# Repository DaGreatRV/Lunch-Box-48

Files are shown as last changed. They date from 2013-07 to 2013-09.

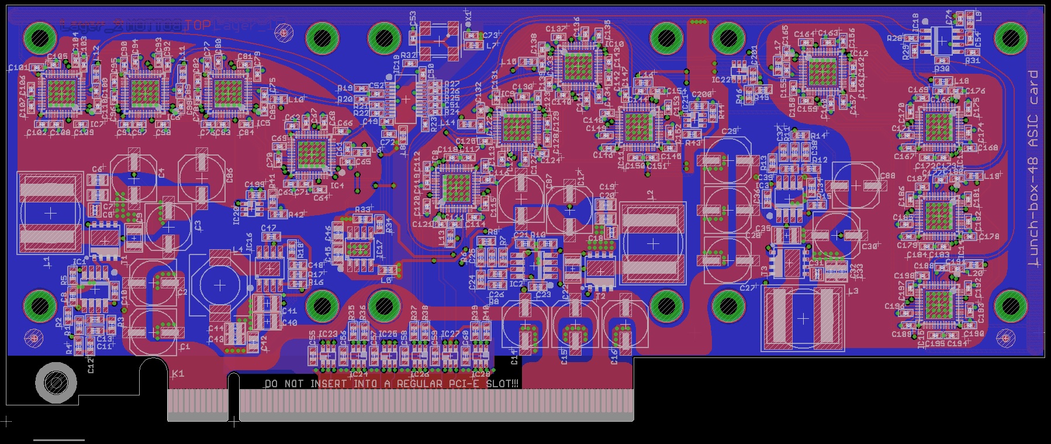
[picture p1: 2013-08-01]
ASIC_board/ASIC_card_overview.jpg

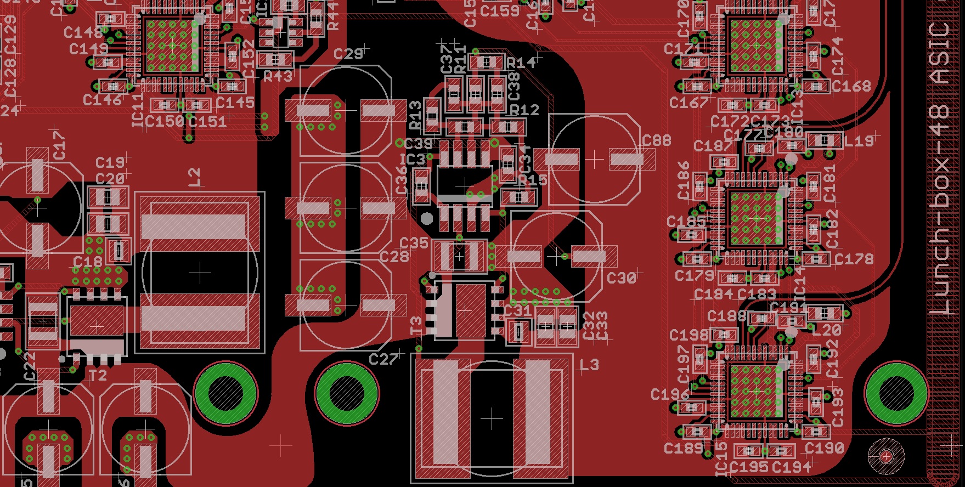
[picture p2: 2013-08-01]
ASIC_board/ASIC_card_detail1.jpg

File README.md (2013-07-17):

Lunch-Box-48
============

A small Avalon based miner

See the thread on bitcointalk/simple machines forum:
https://bitcointalk.org/index.php?topic=219489.0

Terms of use:
I will not take any responsibility for the use, misuse and/or functionality of the work done in this repository.
You are allowed to use and modify the designs in this repository, please do credit me.
If you modify the design(s), please share them and credit me.
You are allowed to use my designs to build a device for private and/or prototype purposes.
If you would like to use this work for commercial purposes(i.e. manufactor and/or selling it), contact me and we can discuss some form of compensation.

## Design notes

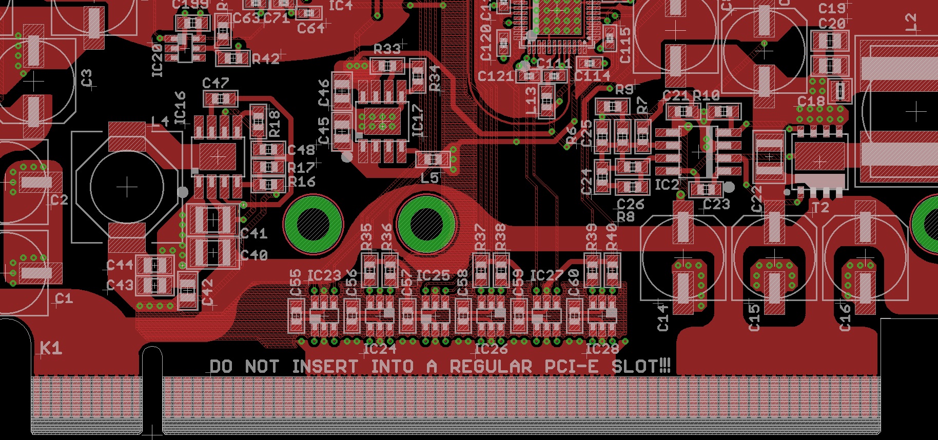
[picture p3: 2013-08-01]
ASIC_board/ASIC_card_detail2.jpg

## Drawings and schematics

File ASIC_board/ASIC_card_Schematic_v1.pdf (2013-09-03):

A

A

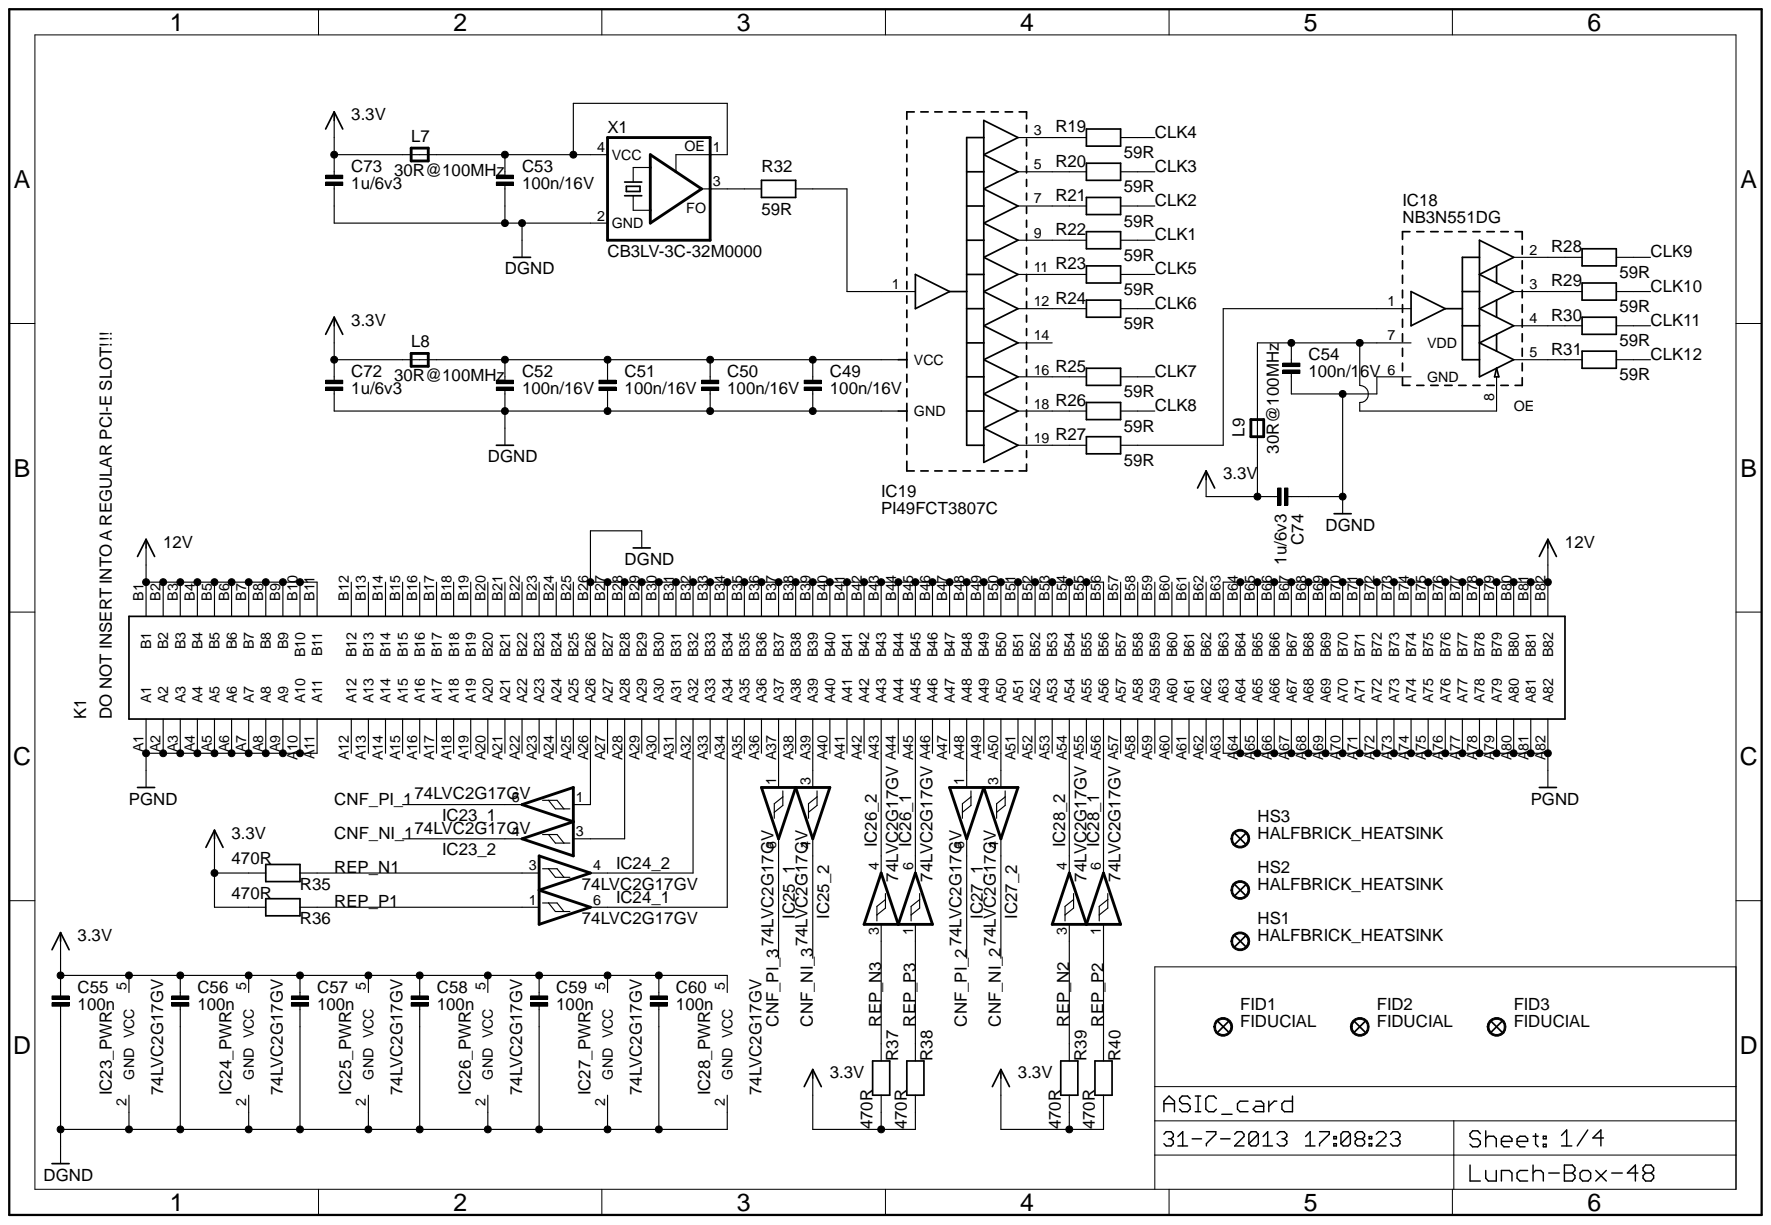
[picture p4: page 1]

DO NOT INSERT INTO A REGULAR PCI-E SLOT!!!

A

A

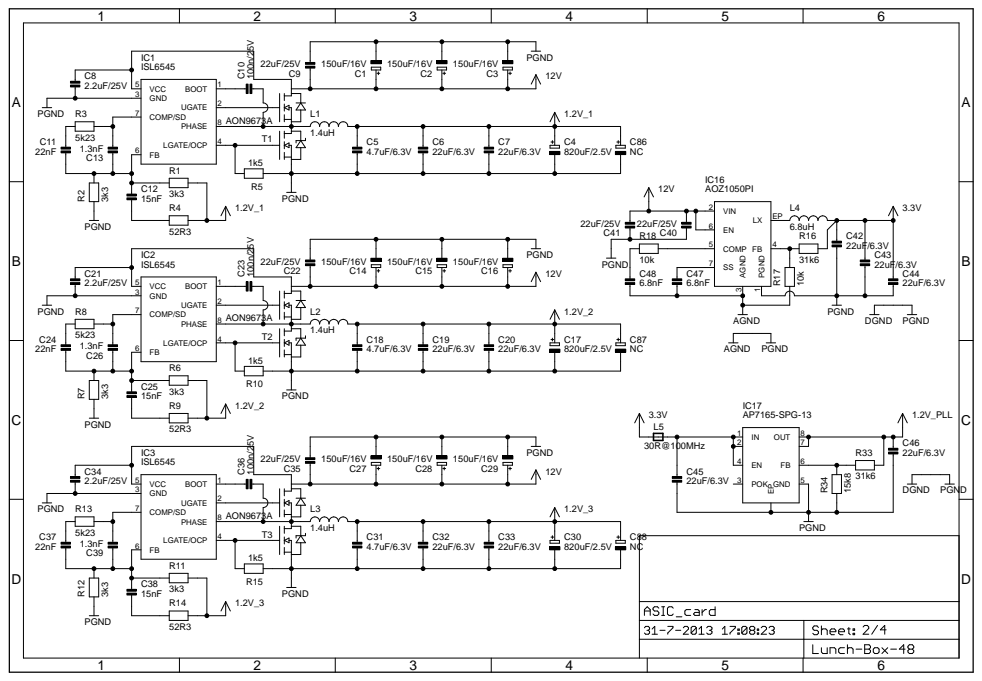
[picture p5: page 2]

A

A

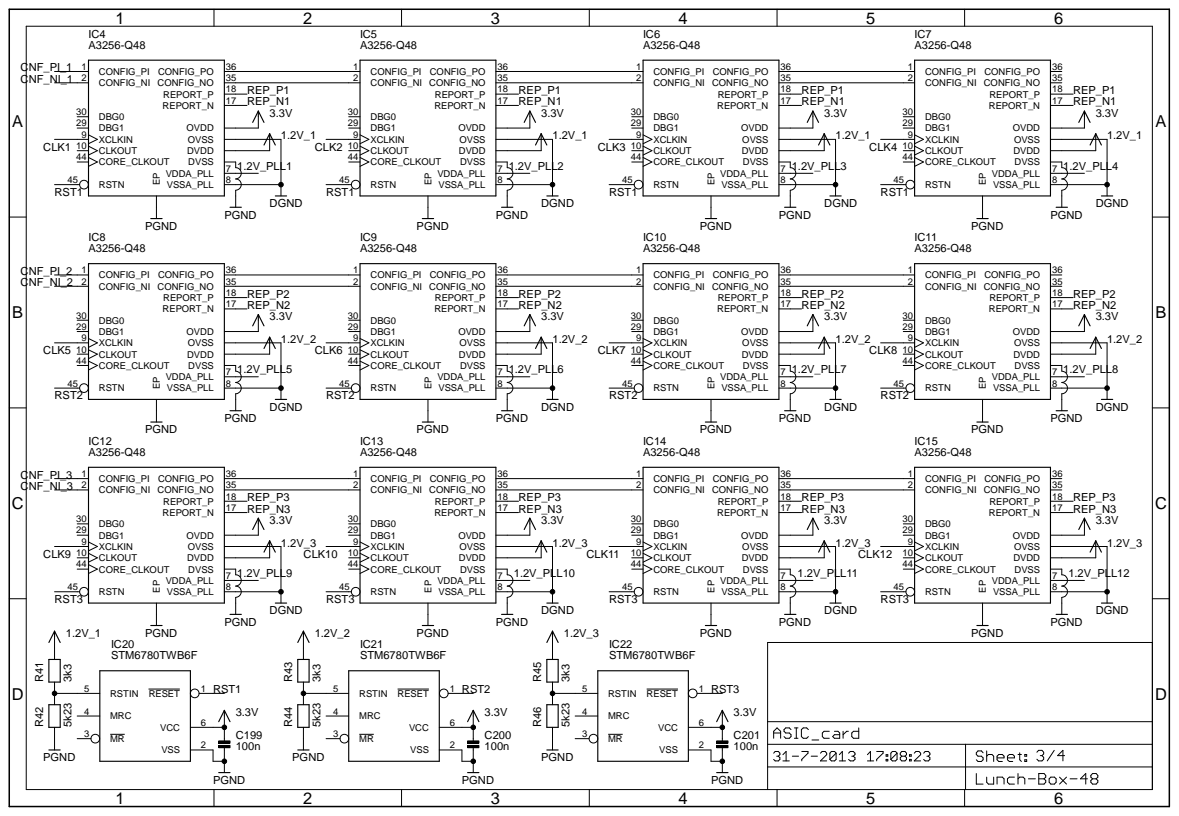
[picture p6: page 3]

A

A

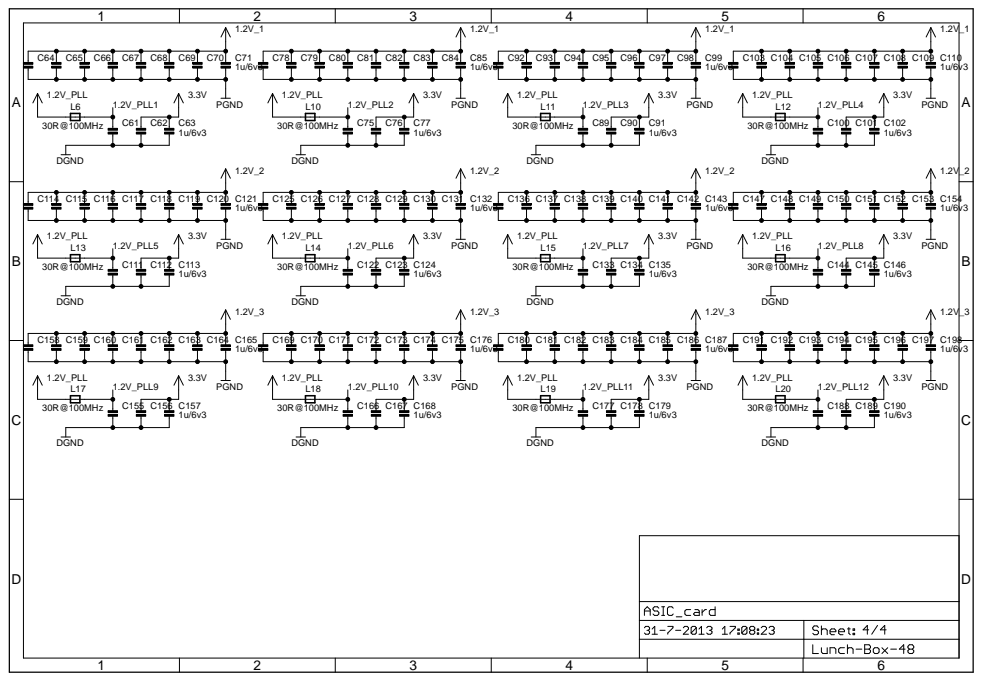
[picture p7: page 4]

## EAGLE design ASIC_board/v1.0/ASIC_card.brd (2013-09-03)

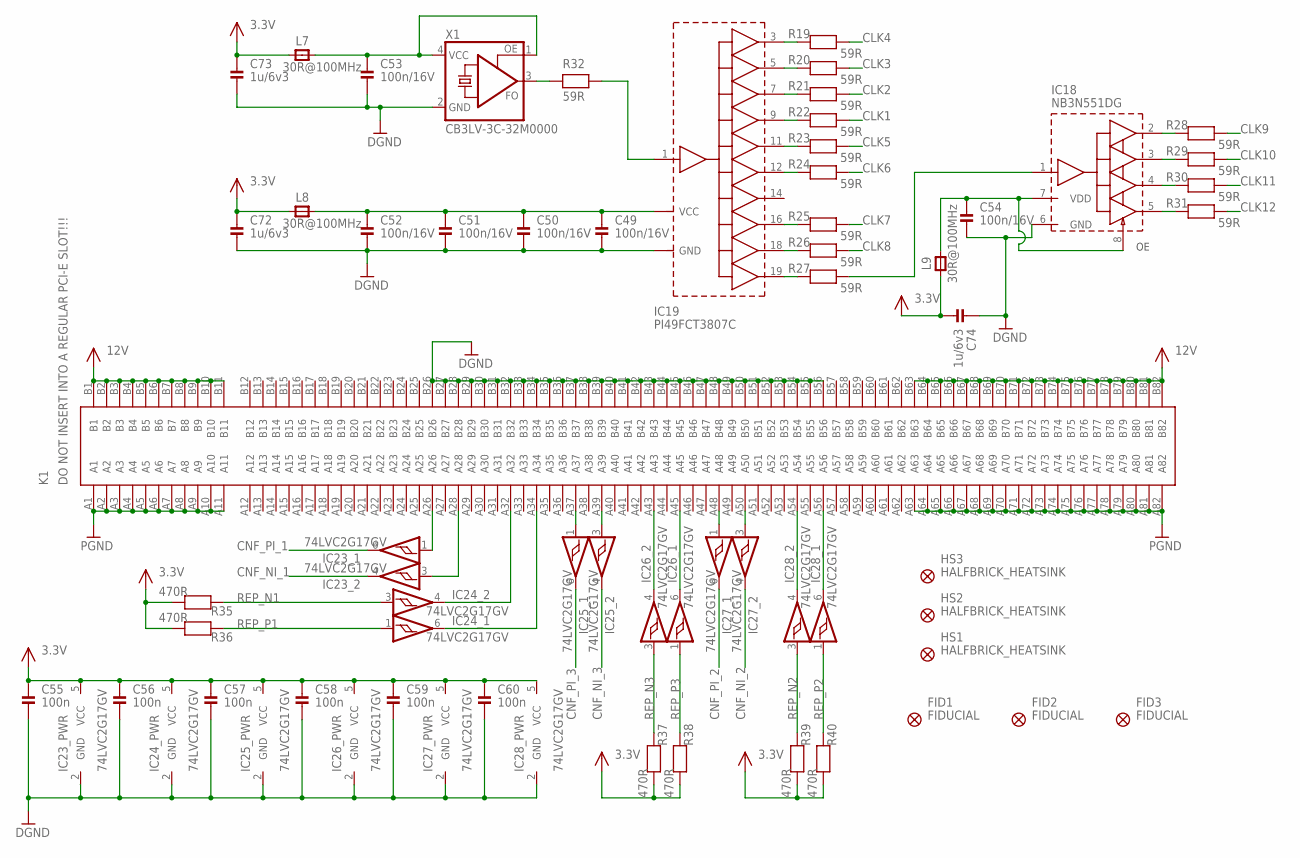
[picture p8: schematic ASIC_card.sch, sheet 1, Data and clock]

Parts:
C49, C50, C51, C52, C53, C54: 100n/16V; 0402
C55, C56, C57, C58, C59, C60: 100n; 0603
C72, C73, C74: 1u/6v3; 0402
FID1, FID2, FID3: FIDUCIAL; FID_1X2,5
HS1, HS2, HS3: HALFBRICK_HEATSINK; 1/2_BRICK_HEATSINK
IC18: NB3N551DG; SO-8
IC19: PI49FCT3807C; SSOP-20
IC23, IC24, IC25, IC26, IC27, IC28: 74LVC2G17GV; SOT23-6
K1: DO NOT INSERT INTO A REGULAR PCI-E SLOT!!!; PCI-E_16X
L7, L8, L9: 30R@100MHz; 0603
R19, R20, R21, R22, R23, R24, R25, R26, R27, R28, R29, R30, R31, R32: 59R; 0402
R35, R36, R37, R38, R39, R40: 470R; 0603
X1: CB3LV-3C-32M0000; 7X5_OSC

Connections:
3.3V: C55.1, C56.1, C57.1, C58.1, C59.1, C60.1, C72.1, C73.1, C74.2, IC23.5 (VCC), IC24.5 (VCC), IC25.5 (VCC), IC26.5 (VCC), IC27.5 (VCC), IC28.5 (VCC), L7.1, L8.1, L9.1, R35.1, R36.1, R37.1, R38.1, R39.1, R40.1; also elsewhere on the board
12V: K1.B1, K1.B2, K1.B3, K1.B4, K1.B5, K1.B6, K1.B7, K1.B8, K1.B9, K1.B10, K1.B11, K1.B63, K1.B64, K1.B65, K1.B66, K1.B67, K1.B68, K1.B69, K1.B70, K1.B71, K1.B72, K1.B73, K1.B74, K1.B75, K1.B76, K1.B77, K1.B78, K1.B79, K1.B80, K1.B81, K1.B82; also elsewhere on the board
CLK1: R22.2; also elsewhere on the board
CLK2: R21.2; also elsewhere on the board
CLK3: R20.2; also elsewhere on the board
CLK4: R19.2; also elsewhere on the board
CLK5: R23.2; also elsewhere on the board
CLK6: R24.2; also elsewhere on the board
CLK7: R25.2; also elsewhere on the board
CLK8: R26.2; also elsewhere on the board
CLK9: R28.2; also elsewhere on the board
CLK10: R29.2; also elsewhere on the board
CLK11: R30.2; also elsewhere on the board
CLK12: R31.2; also elsewhere on the board
CNF_NI_1: IC23.4 (O); also elsewhere on the board
CNF_NI_2: IC27.4 (O); also elsewhere on the board
CNF_NI_3: IC25.4 (O); also elsewhere on the board
CNF_PI_1: IC23.6 (O); also elsewhere on the board
CNF_PI_2: IC27.6 (O); also elsewhere on the board
CNF_PI_3: IC25.6 (O); also elsewhere on the board
DGND: C49.2, C50.2, C51.2, C52.2, C53.2, C54.2, C55.2, C56.2, C57.2, C58.2, C59.2, C60.2, C72.2, C73.2, C74.1, IC18.6 (GND), IC19.2 (GND), IC19.6 (GND), IC19.10 (GND), IC19.13 (GND), IC19.17 (GND), IC23.2 (GND), IC24.2 (GND), IC25.2 (GND), IC26.2 (GND), IC27.2 (GND), IC28.2 (GND), K1.B26, K1.B27, K1.B28, K1.B29, K1.B30, K1.B31, K1.B32, K1.B33, K1.B34, K1.B35, K1.B36, K1.B37, K1.B38, K1.B39, K1.B40, K1.B41, K1.B42, K1.B43, K1.B44, K1.B45, K1.B46, K1.B47, K1.B48, K1.B49, K1.B50, K1.B51, K1.B52, K1.B53, K1.B54, K1.B55, K1.B56, X1.2 (GND); also elsewhere on the board
unnamed: IC23.1 (I), K1.A26
unnamed: IC23.3 (I), K1.A28
unnamed: IC19.18 (B8), R26.1
unnamed: IC19.19 (B9), R27.1
unnamed: IC19.16 (B7), R25.1
unnamed: IC19.12 (B5), R24.1
unnamed: IC19.11 (B4), R23.1
unnamed: IC19.9 (B3), R22.1
unnamed: IC19.7 (B2), R21.1
unnamed: IC19.5 (B1), R20.1
unnamed: IC19.3 (B0), R19.1
unnamed: IC18.2 (Q1), R28.1
unnamed: IC18.3 (Q2), R29.1
unnamed: IC18.4 (Q3), R30.1
unnamed: IC18.5 (Q4), R31.1
unnamed: IC24.4 (O), K1.A32
unnamed: IC24.6 (O), K1.A34
unnamed: IC26.6 (O), K1.A45
unnamed: R32.1, X1.3 (FO)
unnamed: IC19.1 (A), R32.2
unnamed: IC26.4 (O), K1.A43
unnamed: IC28.4 (O), K1.A54
unnamed: IC28.6 (O), K1.A56
unnamed: IC27.1 (I), K1.A48
unnamed: IC27.3 (I), K1.A50
unnamed: C53.1, L7.2, X1.1 (OE), X1.4 (VCC)
unnamed: C54.1, IC18.7 (VDD), IC18.8 (OE), L9.2
unnamed: C49.1, C50.1, C51.1, C52.1, IC19.4 (VCC), IC19.8 (VCC), IC19.15 (VCC), IC19.20 (VCC), L8.2
unnamed: IC18.1 (CLK), R27.2
unnamed: IC25.1 (I), K1.A37
unnamed: IC25.3 (I), K1.A39
PGND: K1.A1, K1.A2, K1.A3, K1.A4, K1.A5, K1.A6, K1.A7, K1.A8, K1.A9, K1.A10, K1.A11, K1.A63, K1.A64, K1.A65, K1.A66, K1.A67, K1.A68, K1.A69, K1.A70, K1.A71, K1.A72, K1.A73, K1.A74, K1.A75, K1.A76, K1.A77, K1.A78, K1.A79, K1.A80, K1.A81, K1.A82; also elsewhere on the board
REP_N1: IC24.3 (I), R35.2; also elsewhere on the board
REP_N2: IC28.3 (I), R39.2; also elsewhere on the board
REP_N3: IC26.3 (I), R37.2; also elsewhere on the board
REP_P1: IC24.1 (I), R36.2; also elsewhere on the board
REP_P2: IC28.1 (I), R40.2; also elsewhere on the board
REP_P3: IC26.1 (I), R38.2; also elsewhere on the board

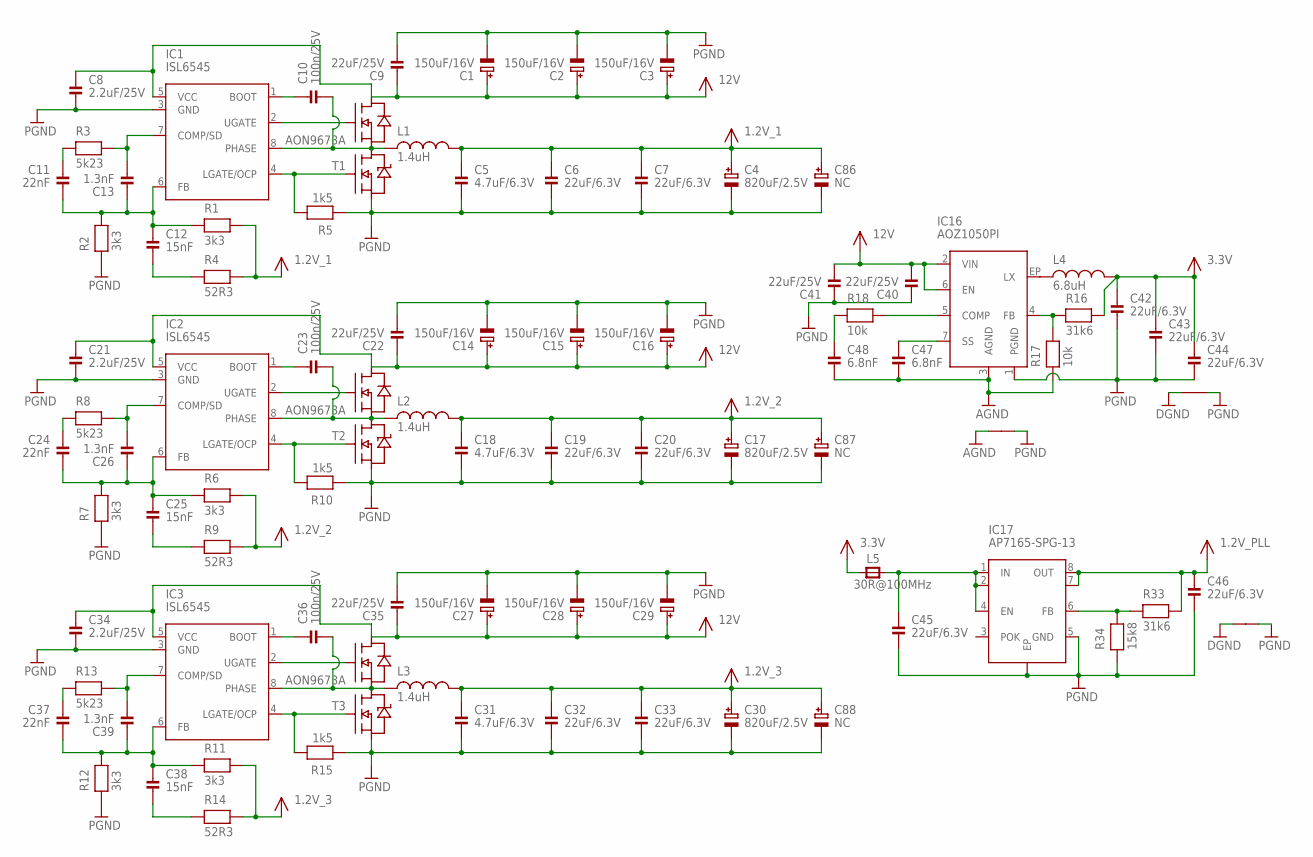
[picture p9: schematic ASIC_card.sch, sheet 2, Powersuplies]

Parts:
C1, C2, C3, C14, C15, C16, C27, C28, C29: 150uF/16V; CAP_POL_8MM
C4, C17, C30: 820uF/2.5V; CAP_POL_8MM
C5, C18, C31: 4.7uF/6.3V; 0306
C6, C7, C19, C20, C32, C33, C42, C43, C44, C45, C46: 22uF/6.3V; 0805
C8, C21, C34: 2.2uF/25V; 0603
C9, C22, C35, C40, C41: 22uF/25V; 1210
C10, C23, C36: 100n/25V; 0603
C11, C24, C37: 22nF; 0603
C12, C25, C38: 15nF; 0603
C13, C26, C39: 1.3nF; 0603
C47, C48: 6.8nF; 0603
C86, C87, C88: NC; CAP_POL_8MM
IC1, IC2, IC3: ISL6545; SO-8_BIGPADS
IC16: AOZ1050PI; SO-8_EP
IC17: AP7165-SPG-13; SO-8_EP
L1, L2, L3: 1.4uH; B82559A0142A013
L4: 6.8uH; SRU1048-6R8Y
L5: 30R@100MHz; 0603
R1, R2, R6, R7, R11, R12: 3k3; 0603
R3, R8, R13: 5k23; 0603
R4, R9, R14: 52R3; 0603
R5, R10, R15: 1k5; 0603
R16, R33: 31k6; 0603
R17, R18: 10k; 0603
R34: 15k8; 0603
T1, T2, T3: AON9673A; DFN5X6
VIA1, VIA2, VIA3: VIA

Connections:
1.2V_1: C4.P$1 (+), C5.1, C6.1, C7.1, C86.P$1 (+), L1.2, R1.2, R4.2; also elsewhere on the board
1.2V_2: C17.P$1 (+), C18.1, C19.1, C20.1, C87.P$1 (+), L2.2, R6.2, R9.2; also elsewhere on the board
1.2V_3: C30.P$1 (+), C31.1, C32.1, C33.1, C88.P$1 (+), L3.2, R11.2, R14.2; also elsewhere on the board
1.2V_PLL: C46.1, IC17.7 (OUT1), IC17.8 (OUT), R33.2; also elsewhere on the board
3.3V: C42.1, C43.1, C44.1, L4.2, L5.1, R16.2; also elsewhere on the board
12V: C1.P$1 (+), C2.P$1 (+), C3.P$1 (+), C8.1, C9.1, C14.P$1 (+), C15.P$1 (+), C16.P$1 (+), C21.1, C22.1, C27.P$1 (+), C28.P$1 (+), C29.P$1 (+), C34.1, C35.1, C40.2, C41.2, IC1.5 (VCC), IC2.5 (VCC), IC3.5 (VCC), IC16.2 (VIN), IC16.6 (EN), T1.D1, T2.D1, T3.D1; also elsewhere on the board
AGND: C47.2, C48.2, IC16.3 (AGND), R17.1, VIA1.P$1
DGND: VIA2.P$1, VIA3.P$1; also elsewhere on the board
unnamed: C12.2, R4.1
unnamed: IC1.2 (UGATE), T1.1 (G1)
unnamed: IC1.4 (LGATE/OCP), R5.2, T1.8 (G2)
unnamed: C10.1, IC1.1 (BOOT)
unnamed: C13.2, IC1.7 (COMP/SD), R3.2
unnamed: C11.1, R3.1
unnamed: C11.2, C12.1, C13.1, IC1.6 (FB), R1.1, R2.2
unnamed: C10.2, IC1.8 (PHASE), L1.1, T1.S1_D2
unnamed: IC3.2 (UGATE), T3.1 (G1)
unnamed: IC2.2 (UGATE), T2.1 (G1)
unnamed: IC2.4 (LGATE/OCP), R10.2, T2.8 (G2)
unnamed: C23.2, IC2.8 (PHASE), L2.1, T2.S1_D2
unnamed: C23.1, IC2.1 (BOOT)
unnamed: C26.2, IC2.7 (COMP/SD), R8.2
unnamed: C24.1, R8.1
unnamed: C24.2, C25.1, C26.1, IC2.6 (FB), R6.1, R7.2
unnamed: C25.2, R9.1
unnamed: IC3.4 (LGATE/OCP), R15.2, T3.8 (G2)
unnamed: C36.2, IC3.8 (PHASE), L3.1, T3.S1_D2
unnamed: C36.1, IC3.1 (BOOT)
unnamed: C39.2, IC3.7 (COMP/SD), R13.2
unnamed: C37.1, R13.1
unnamed: C37.2, C38.1, C39.1, IC3.6 (FB), R11.1, R12.2
unnamed: C38.2, R14.1
unnamed: C47.1, IC16.7 (SS)
unnamed: C45.1, IC17.1 (IN), IC17.2 (IN1), IC17.4 (EN), L5.2
unnamed: C48.1, R18.1
unnamed: IC16.5 (COMP), R18.2
unnamed: IC16.4 (FB), R16.1, R17.2
unnamed: IC16.EP (LX), L4.1
unnamed: IC17.6 (FB), R33.1, R34.2
PGND: C1.P$2 (-), C2.P$2 (-), C3.P$2 (-), C4.P$2 (-), C5.2, C6.2, C7.2, C8.2, C9.2, C14.P$2 (-), C15.P$2 (-), C16.P$2 (-), C17.P$2 (-), C18.2, C19.2, C20.2, C21.2, C22.2, C27.P$2 (-), C28.P$2 (-), C29.P$2 (-), C30.P$2 (-), C31.2, C32.2, C33.2, C34.2, C35.2, C40.1, C41.1, C42.2, C43.2, C44.2, C45.2, C46.2, C86.P$2 (-), C87.P$2 (-), C88.P$2 (-), IC1.3 (GND), IC2.3 (GND), IC3.3 (GND), IC16.1 (PGND), IC17.5 (GND), IC17.EP, R2.1, R5.1, R7.1, R10.1, R12.1, R15.1, R34.1, T1.5 (S2), T1.6 (S2), T1.7 (S2), T2.5 (S2), T2.6 (S2), T2.7 (S2), T3.5 (S2), T3.6 (S2), T3.7 (S2), VIA1.P$2, VIA2.P$2, VIA3.P$2; also elsewhere on the board

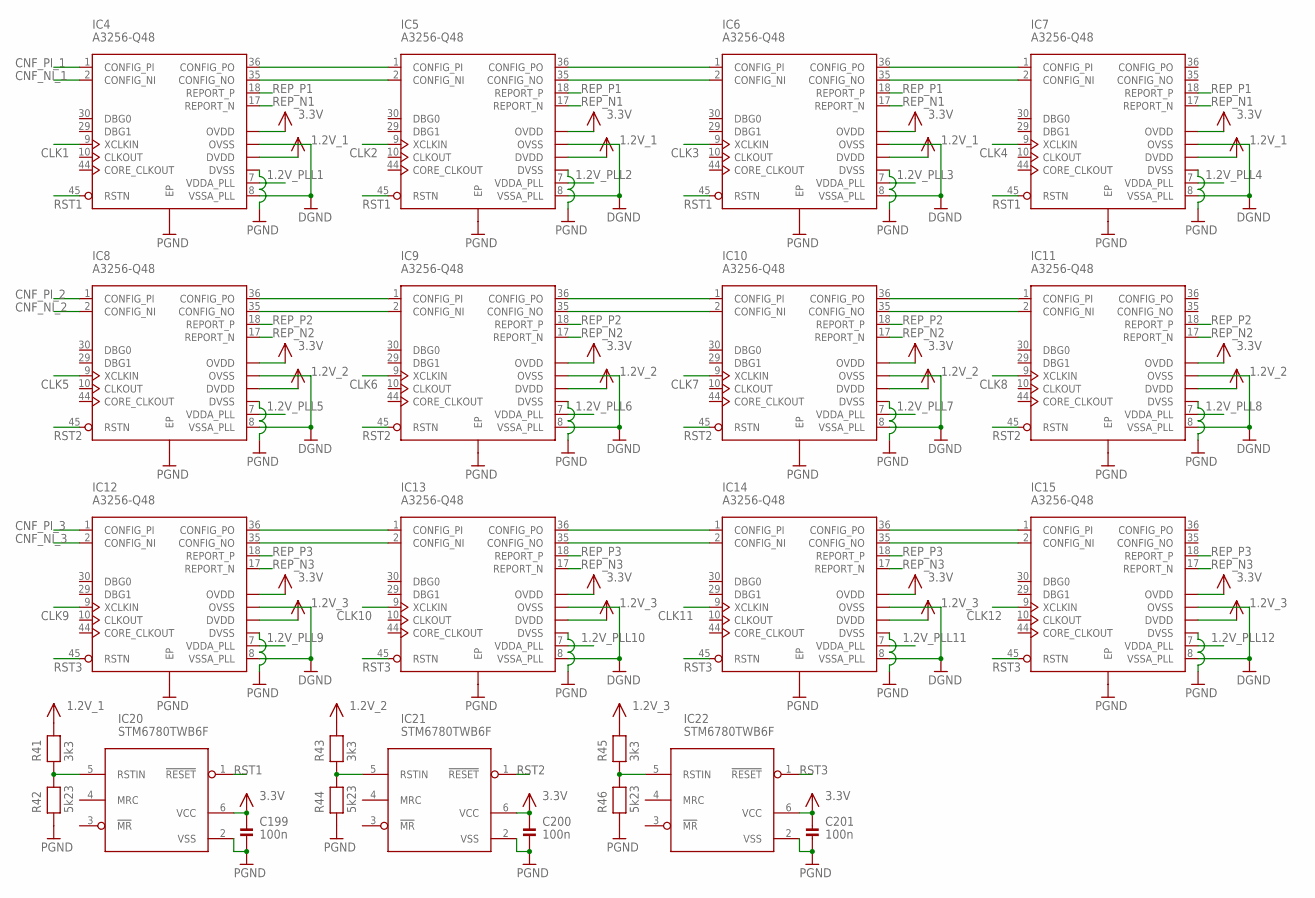
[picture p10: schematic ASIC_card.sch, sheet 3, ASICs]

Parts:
C199, C200, C201: 100n; 0603
IC4, IC5, IC6, IC7, IC8, IC9, IC10, IC11, IC12, IC13, IC14, IC15: A3256-Q48; QFN48_EP
IC20, IC21, IC22: STM6780TWB6F; SOT23-6
R41, R43, R45: 3k3; 0603
R42, R44, R46: 5k23; 0603

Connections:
1.2V_1: IC4.3 (DVDD), IC4.4 (DVDD), IC4.6 (DVDD), IC4.11 (DVDD), IC4.12 (DVDD), IC4.13 (DVDD), IC4.14 (DVDD), IC4.15 (DVDD), IC4.16 (DVDD), IC4.19 (DVDD), IC4.21 (DVDD), IC4.22 (DVDD), IC4.25 (DVDD), IC4.26 (DVDD), IC4.27 (DVDD), IC4.28 (DVDD), IC4.31 (DVDD), IC4.33 (DVDD), IC4.34 (DVDD), IC4.39 (DVDD), IC4.40 (DVDD), IC4.41 (DVDD), IC4.43 (DVDD), IC4.46 (DVDD), IC4.47 (DVDD), IC4.48 (DVDD), IC5.3 (DVDD), IC5.4 (DVDD), IC5.6 (DVDD), IC5.11 (DVDD), IC5.12 (DVDD), IC5.13 (DVDD), IC5.14 (DVDD), IC5.15 (DVDD), IC5.16 (DVDD), IC5.19 (DVDD), IC5.21 (DVDD), IC5.22 (DVDD), IC5.25 (DVDD), IC5.26 (DVDD), IC5.27 (DVDD), IC5.28 (DVDD), IC5.31 (DVDD), IC5.33 (DVDD), IC5.34 (DVDD), IC5.39 (DVDD), IC5.40 (DVDD), IC5.41 (DVDD), IC5.43 (DVDD), IC5.46 (DVDD), IC5.47 (DVDD), IC5.48 (DVDD), IC6.3 (DVDD), IC6.4 (DVDD), IC6.6 (DVDD), IC6.11 (DVDD), IC6.12 (DVDD), IC6.13 (DVDD), IC6.14 (DVDD), IC6.15 (DVDD), IC6.16 (DVDD), IC6.19 (DVDD), IC6.21 (DVDD), IC6.22 (DVDD), IC6.25 (DVDD), IC6.26 (DVDD), IC6.27 (DVDD), IC6.28 (DVDD), IC6.31 (DVDD), IC6.33 (DVDD), IC6.34 (DVDD), IC6.39 (DVDD), IC6.40 (DVDD), IC6.41 (DVDD), IC6.43 (DVDD), IC6.46 (DVDD), IC6.47 (DVDD), IC6.48 (DVDD), IC7.3 (DVDD), IC7.4 (DVDD), IC7.6 (DVDD), IC7.11 (DVDD), IC7.12 (DVDD), IC7.13 (DVDD), IC7.14 (DVDD), IC7.15 (DVDD), IC7.16 (DVDD), IC7.19 (DVDD), IC7.21 (DVDD), IC7.22 (DVDD), IC7.25 (DVDD), IC7.26 (DVDD), IC7.27 (DVDD), IC7.28 (DVDD), IC7.31 (DVDD), IC7.33 (DVDD), IC7.34 (DVDD), IC7.39 (DVDD), IC7.40 (DVDD), IC7.41 (DVDD), IC7.43 (DVDD), IC7.46 (DVDD), IC7.47 (DVDD), IC7.48 (DVDD), R41.2; also elsewhere on the board
1.2V_2: IC8.3 (DVDD), IC8.4 (DVDD), IC8.6 (DVDD), IC8.11 (DVDD), IC8.12 (DVDD), IC8.13 (DVDD), IC8.14 (DVDD), IC8.15 (DVDD), IC8.16 (DVDD), IC8.19 (DVDD), IC8.21 (DVDD), IC8.22 (DVDD), IC8.25 (DVDD), IC8.26 (DVDD), IC8.27 (DVDD), IC8.28 (DVDD), IC8.31 (DVDD), IC8.33 (DVDD), IC8.34 (DVDD), IC8.39 (DVDD), IC8.40 (DVDD), IC8.41 (DVDD), IC8.43 (DVDD), IC8.46 (DVDD), IC8.47 (DVDD), IC8.48 (DVDD), IC9.3 (DVDD), IC9.4 (DVDD), IC9.6 (DVDD), IC9.11 (DVDD), IC9.12 (DVDD), IC9.13 (DVDD), IC9.14 (DVDD), IC9.15 (DVDD), IC9.16 (DVDD), IC9.19 (DVDD), IC9.21 (DVDD), IC9.22 (DVDD), IC9.25 (DVDD), IC9.26 (DVDD), IC9.27 (DVDD), IC9.28 (DVDD), IC9.31 (DVDD), IC9.33 (DVDD), IC9.34 (DVDD), IC9.39 (DVDD), IC9.40 (DVDD), IC9.41 (DVDD), IC9.43 (DVDD), IC9.46 (DVDD), IC9.47 (DVDD), IC9.48 (DVDD), IC10.3 (DVDD), IC10.4 (DVDD), IC10.6 (DVDD), IC10.11 (DVDD), IC10.12 (DVDD), IC10.13 (DVDD), IC10.14 (DVDD), IC10.15 (DVDD), IC10.16 (DVDD), IC10.19 (DVDD), IC10.21 (DVDD), IC10.22 (DVDD), IC10.25 (DVDD), IC10.26 (DVDD), IC10.27 (DVDD), IC10.28 (DVDD), IC10.31 (DVDD), IC10.33 (DVDD), IC10.34 (DVDD), IC10.39 (DVDD), IC10.40 (DVDD), IC10.41 (DVDD), IC10.43 (DVDD), IC10.46 (DVDD), IC10.47 (DVDD), IC10.48 (DVDD), IC11.3 (DVDD), IC11.4 (DVDD), IC11.6 (DVDD), IC11.11 (DVDD), IC11.12 (DVDD), IC11.13 (DVDD), IC11.14 (DVDD), IC11.15 (DVDD), IC11.16 (DVDD), IC11.19 (DVDD), IC11.21 (DVDD), IC11.22 (DVDD), IC11.25 (DVDD), IC11.26 (DVDD), IC11.27 (DVDD), IC11.28 (DVDD), IC11.31 (DVDD), IC11.33 (DVDD), IC11.34 (DVDD), IC11.39 (DVDD), IC11.40 (DVDD), IC11.41 (DVDD), IC11.43 (DVDD), IC11.46 (DVDD), IC11.47 (DVDD), IC11.48 (DVDD), R43.2; also elsewhere on the board
1.2V_3: IC12.3 (DVDD), IC12.4 (DVDD), IC12.6 (DVDD), IC12.11 (DVDD), IC12.12 (DVDD), IC12.13 (DVDD), IC12.14 (DVDD), IC12.15 (DVDD), IC12.16 (DVDD), IC12.19 (DVDD), IC12.21 (DVDD), IC12.22 (DVDD), IC12.25 (DVDD), IC12.26 (DVDD), IC12.27 (DVDD), IC12.28 (DVDD), IC12.31 (DVDD), IC12.33 (DVDD), IC12.34 (DVDD), IC12.39 (DVDD), IC12.40 (DVDD), IC12.41 (DVDD), IC12.43 (DVDD), IC12.46 (DVDD), IC12.47 (DVDD), IC12.48 (DVDD), IC13.3 (DVDD), IC13.4 (DVDD), IC13.6 (DVDD), IC13.11 (DVDD), IC13.12 (DVDD), IC13.13 (DVDD), IC13.14 (DVDD), IC13.15 (DVDD), IC13.16 (DVDD), IC13.19 (DVDD), IC13.21 (DVDD), IC13.22 (DVDD), IC13.25 (DVDD), IC13.26 (DVDD), IC13.27 (DVDD), IC13.28 (DVDD), IC13.31 (DVDD), IC13.33 (DVDD), IC13.34 (DVDD), IC13.39 (DVDD), IC13.40 (DVDD), IC13.41 (DVDD), IC13.43 (DVDD), IC13.46 (DVDD), IC13.47 (DVDD), IC13.48 (DVDD), IC14.3 (DVDD), IC14.4 (DVDD), IC14.6 (DVDD), IC14.11 (DVDD), IC14.12 (DVDD), IC14.13 (DVDD), IC14.14 (DVDD), IC14.15 (DVDD), IC14.16 (DVDD), IC14.19 (DVDD), IC14.21 (DVDD), IC14.22 (DVDD), IC14.25 (DVDD), IC14.26 (DVDD), IC14.27 (DVDD), IC14.28 (DVDD), IC14.31 (DVDD), IC14.33 (DVDD), IC14.34 (DVDD), IC14.39 (DVDD), IC14.40 (DVDD), IC14.41 (DVDD), IC14.43 (DVDD), IC14.46 (DVDD), IC14.47 (DVDD), IC14.48 (DVDD), IC15.3 (DVDD), IC15.4 (DVDD), IC15.6 (DVDD), IC15.11 (DVDD), IC15.12 (DVDD), IC15.13 (DVDD), IC15.14 (DVDD), IC15.15 (DVDD), IC15.16 (DVDD), IC15.19 (DVDD), IC15.21 (DVDD), IC15.22 (DVDD), IC15.25 (DVDD), IC15.26 (DVDD), IC15.27 (DVDD), IC15.28 (DVDD), IC15.31 (DVDD), IC15.33 (DVDD), IC15.34 (DVDD), IC15.39 (DVDD), IC15.40 (DVDD), IC15.41 (DVDD), IC15.43 (DVDD), IC15.46 (DVDD), IC15.47 (DVDD), IC15.48 (DVDD), R45.2; also elsewhere on the board
1.2V_PLL1: IC4.7 (VDDA_PLL); also elsewhere on the board
1.2V_PLL2: IC5.7 (VDDA_PLL); also elsewhere on the board
1.2V_PLL3: IC6.7 (VDDA_PLL); also elsewhere on the board
1.2V_PLL4: IC7.7 (VDDA_PLL); also elsewhere on the board
1.2V_PLL5: IC8.7 (VDDA_PLL); also elsewhere on the board
1.2V_PLL6: IC9.7 (VDDA_PLL); also elsewhere on the board
1.2V_PLL7: IC10.7 (VDDA_PLL); also elsewhere on the board
1.2V_PLL8: IC11.7 (VDDA_PLL); also elsewhere on the board
1.2V_PLL9: IC12.7 (VDDA_PLL); also elsewhere on the board
1.2V_PLL10: IC13.7 (VDDA_PLL); also elsewhere on the board
1.2V_PLL11: IC14.7 (VDDA_PLL); also elsewhere on the board
1.2V_PLL12: IC15.7 (VDDA_PLL); also elsewhere on the board
3.3V: C199.1, C200.1, C201.1, IC4.24 (OVDD), IC4.37 (OVDD), IC5.24 (OVDD), IC5.37 (OVDD), IC6.24 (OVDD), IC6.37 (OVDD), IC7.24 (OVDD), IC7.37 (OVDD), IC8.24 (OVDD), IC8.37 (OVDD), IC9.24 (OVDD), IC9.37 (OVDD), IC10.24 (OVDD), IC10.37 (OVDD), IC11.24 (OVDD), IC11.37 (OVDD), IC12.24 (OVDD), IC12.37 (OVDD), IC13.24 (OVDD), IC13.37 (OVDD), IC14.24 (OVDD), IC14.37 (OVDD), IC15.24 (OVDD), IC15.37 (OVDD), IC20.6 (VCC), IC21.6 (VCC), IC22.6 (VCC); also elsewhere on the board
CLK1: IC4.9 (XCLKIN); also elsewhere on the board
CLK2: IC5.9 (XCLKIN); also elsewhere on the board
CLK3: IC6.9 (XCLKIN); also elsewhere on the board
CLK4: IC7.9 (XCLKIN); also elsewhere on the board
CLK5: IC8.9 (XCLKIN); also elsewhere on the board
CLK6: IC9.9 (XCLKIN); also elsewhere on the board
CLK7: IC10.9 (XCLKIN); also elsewhere on the board
CLK8: IC11.9 (XCLKIN); also elsewhere on the board
CLK9: IC12.9 (XCLKIN); also elsewhere on the board
CLK10: IC13.9 (XCLKIN); also elsewhere on the board
CLK11: IC14.9 (XCLKIN); also elsewhere on the board
CLK12: IC15.9 (XCLKIN); also elsewhere on the board
CNF_NI_1: IC4.2 (CONFIG_NI); also elsewhere on the board
CNF_NI_2: IC8.2 (CONFIG_NI); also elsewhere on the board
CNF_NI_3: IC12.2 (CONFIG_NI); also elsewhere on the board
CNF_PI_1: IC4.1 (CONFIG_PI); also elsewhere on the board
CNF_PI_2: IC8.1 (CONFIG_PI); also elsewhere on the board
CNF_PI_3: IC12.1 (CONFIG_PI); also elsewhere on the board
DGND: IC4.8 (VSSA_PLL), IC4.23 (OVSS), IC4.38 (OVSS), IC5.8 (VSSA_PLL), IC5.23 (OVSS), IC5.38 (OVSS), IC6.8 (VSSA_PLL), IC6.23 (OVSS), IC6.38 (OVSS), IC7.8 (VSSA_PLL), IC7.23 (OVSS), IC7.38 (OVSS), IC8.8 (VSSA_PLL), IC8.23 (OVSS), IC8.38 (OVSS), IC9.8 (VSSA_PLL), IC9.23 (OVSS), IC9.38 (OVSS), IC10.8 (VSSA_PLL), IC10.23 (OVSS), IC10.38 (OVSS), IC11.8 (VSSA_PLL), IC11.23 (OVSS), IC11.38 (OVSS), IC12.8 (VSSA_PLL), IC12.23 (OVSS), IC12.38 (OVSS), IC13.8 (VSSA_PLL), IC13.23 (OVSS), IC13.38 (OVSS), IC14.8 (VSSA_PLL), IC14.23 (OVSS), IC14.38 (OVSS), IC15.8 (VSSA_PLL), IC15.23 (OVSS), IC15.38 (OVSS); also elsewhere on the board
unnamed: IC4.36 (CONFIG_PO), IC5.1 (CONFIG_PI)
unnamed: IC4.35 (CONFIG_NO), IC5.2 (CONFIG_NI)
unnamed: IC5.36 (CONFIG_PO), IC6.1 (CONFIG_PI)
unnamed: IC5.35 (CONFIG_NO), IC6.2 (CONFIG_NI)
unnamed: IC6.36 (CONFIG_PO), IC7.1 (CONFIG_PI)
unnamed: IC6.35 (CONFIG_NO), IC7.2 (CONFIG_NI)
unnamed: IC8.36 (CONFIG_PO), IC9.1 (CONFIG_PI)
unnamed: IC8.35 (CONFIG_NO), IC9.2 (CONFIG_NI)
unnamed: IC9.36 (CONFIG_PO), IC10.1 (CONFIG_PI)
unnamed: IC9.35 (CONFIG_NO), IC10.2 (CONFIG_NI)
unnamed: IC10.36 (CONFIG_PO), IC11.1 (CONFIG_PI)
unnamed: IC10.35 (CONFIG_NO), IC11.2 (CONFIG_NI)
unnamed: IC14.36 (CONFIG_PO), IC15.1 (CONFIG_PI)
unnamed: IC14.35 (CONFIG_NO), IC15.2 (CONFIG_NI)
unnamed: IC13.36 (CONFIG_PO), IC14.1 (CONFIG_PI)
unnamed: IC13.35 (CONFIG_NO), IC14.2 (CONFIG_NI)
unnamed: IC12.36 (CONFIG_PO), IC13.1 (CONFIG_PI)
unnamed: IC12.35 (CONFIG_NO), IC13.2 (CONFIG_NI)
unnamed: IC20.5 (RSTIN), R41.1, R42.2
unnamed: IC21.5 (RSTIN), R43.1, R44.2
unnamed: IC22.5 (RSTIN), R45.1, R46.2
PGND: C199.2, C200.2, C201.2, IC4.5 (DVSS), IC4.20 (DVSS), IC4.32 (DVSS), IC4.42 (DVSS), IC4.EP, IC5.5 (DVSS), IC5.20 (DVSS), IC5.32 (DVSS), IC5.42 (DVSS), IC5.EP, IC6.5 (DVSS), IC6.20 (DVSS), IC6.32 (DVSS), IC6.42 (DVSS), IC6.EP, IC7.5 (DVSS), IC7.20 (DVSS), IC7.32 (DVSS), IC7.42 (DVSS), IC7.EP, IC8.5 (DVSS), IC8.20 (DVSS), IC8.32 (DVSS), IC8.42 (DVSS), IC8.EP, IC9.5 (DVSS), IC9.20 (DVSS), IC9.32 (DVSS), IC9.42 (DVSS), IC9.EP, IC10.5 (DVSS), IC10.20 (DVSS), IC10.32 (DVSS), IC10.42 (DVSS), IC10.EP, IC11.5 (DVSS), IC11.20 (DVSS), IC11.32 (DVSS), IC11.42 (DVSS), IC11.EP, IC12.5 (DVSS), IC12.20 (DVSS), IC12.32 (DVSS), IC12.42 (DVSS), IC12.EP, IC13.5 (DVSS), IC13.20 (DVSS), IC13.32 (DVSS), IC13.42 (DVSS), IC13.EP, IC14.5 (DVSS), IC14.20 (DVSS), IC14.32 (DVSS), IC14.42 (DVSS), IC14.EP, IC15.5 (DVSS), IC15.20 (DVSS), IC15.32 (DVSS), IC15.42 (DVSS), IC15.EP, IC20.2 (VSS), IC21.2 (VSS), IC22.2 (VSS), R42.1, R44.1, R46.1; also elsewhere on the board
REP_N1: IC4.17 (REPORT_N), IC5.17 (REPORT_N), IC6.17 (REPORT_N), IC7.17 (REPORT_N); also elsewhere on the board
REP_N2: IC8.17 (REPORT_N), IC9.17 (REPORT_N), IC10.17 (REPORT_N), IC11.17 (REPORT_N); also elsewhere on the board
REP_N3: IC12.17 (REPORT_N), IC13.17 (REPORT_N), IC14.17 (REPORT_N), IC15.17 (REPORT_N); also elsewhere on the board
REP_P1: IC4.18 (REPORT_P), IC5.18 (REPORT_P), IC6.18 (REPORT_P), IC7.18 (REPORT_P); also elsewhere on the board
REP_P2: IC8.18 (REPORT_P), IC9.18 (REPORT_P), IC10.18 (REPORT_P), IC11.18 (REPORT_P); also elsewhere on the board
REP_P3: IC12.18 (REPORT_P), IC13.18 (REPORT_P), IC14.18 (REPORT_P), IC15.18 (REPORT_P); also elsewhere on the board
RST1: IC4.45 (RSTN), IC5.45 (RSTN), IC6.45 (RSTN), IC7.45 (RSTN), IC20.1 (!RESET!)
RST2: IC8.45 (RSTN), IC9.45 (RSTN), IC10.45 (RSTN), IC11.45 (RSTN), IC21.1 (!RESET!)
RST3: IC12.45 (RSTN), IC13.45 (RSTN), IC14.45 (RSTN), IC15.45 (RSTN), IC22.1 (!RESET!)

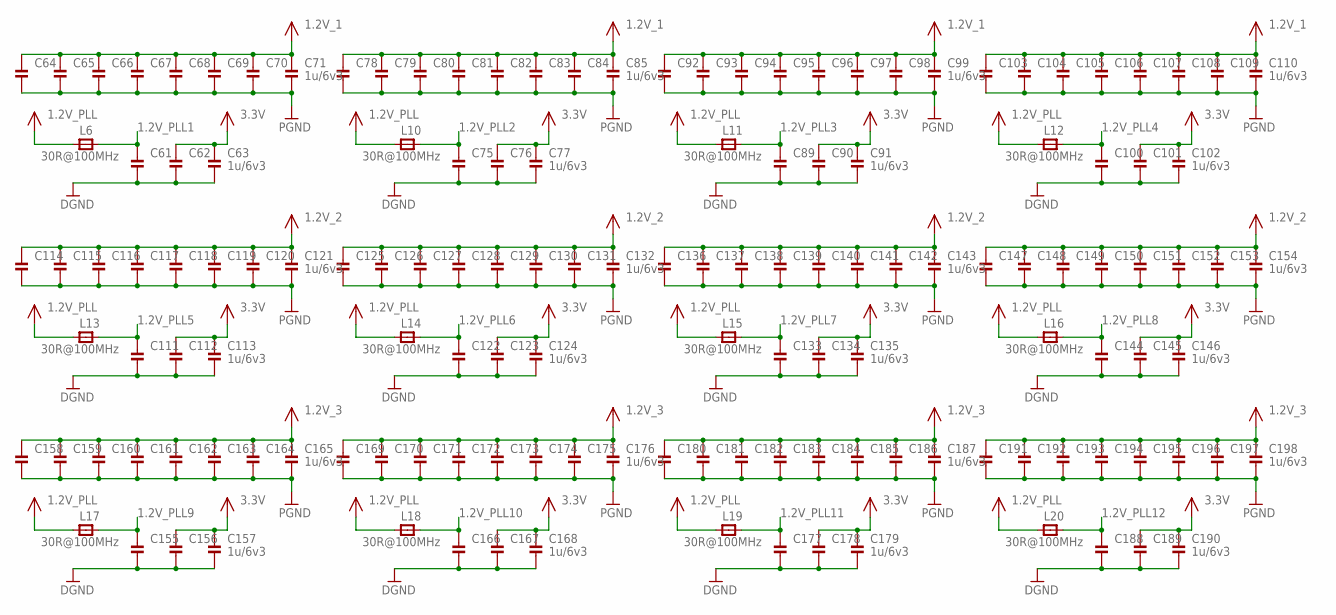
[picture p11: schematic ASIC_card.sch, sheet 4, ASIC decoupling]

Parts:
C61, C62, C63, C64, C65, C66, C67, C68, C69, C70, C71, C75, C76, C77, C78, C79, C80, C81, C82, C83, C84, C85, C89, C90, C91, C92, C93, C94, C95, C96, C97, C98, C99, C100, C101, C102, C103, C104, C105, C106, C107, C108, C109, C110, C111, C112, C113, C114, C115, C116, C117, C118, C119, C120, C121, C122, C123, C124, C125, C126, C127, C128, C129, C130, C131, C132, C133, C134, C135, C136, C137, C138, C139, C140, C141, C142, C143, C144, C145, C146, C147, C148, C149, C150, C151, C152, C153, C154, C155, C156, C157, C158, C159, C160, C161, C162, C163, C164, C165, C166, C167, C168, C169, C170, C171, C172, C173, C174, C175, C176, C177, C178, C179, C180, C181, C182, C183, C184, C185, C186, C187, C188, C189, C190, C191, C192, C193, C194, C195, C196, C197, C198: 1u/6v3; 0402
L6, L10, L11, L12, L13, L14, L15, L16, L17, L18, L19, L20: 30R@100MHz; 0603

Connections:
1.2V_1: C64.1, C65.1, C66.1, C67.1, C68.1, C69.1, C70.1, C71.1, C78.1, C79.1, C80.1, C81.1, C82.1, C83.1, C84.1, C85.1, C92.1, C93.1, C94.1, C95.1, C96.1, C97.1, C98.1, C99.1, C103.1, C104.1, C105.1, C106.1, C107.1, C108.1, C109.1, C110.1; also elsewhere on the board
1.2V_2: C114.1, C115.1, C116.1, C117.1, C118.1, C119.1, C120.1, C121.1, C125.1, C126.1, C127.1, C128.1, C129.1, C130.1, C131.1, C132.1, C136.1, C137.1, C138.1, C139.1, C140.1, C141.1, C142.1, C143.1, C147.1, C148.1, C149.1, C150.1, C151.1, C152.1, C153.1, C154.1; also elsewhere on the board
1.2V_3: C158.1, C159.1, C160.1, C161.1, C162.1, C163.1, C164.1, C165.1, C169.1, C170.1, C171.1, C172.1, C173.1, C174.1, C175.1, C176.1, C180.1, C181.1, C182.1, C183.1, C184.1, C185.1, C186.1, C187.1, C191.1, C192.1, C193.1, C194.1, C195.1, C196.1, C197.1, C198.1; also elsewhere on the board
1.2V_PLL: L6.1, L10.1, L11.1, L12.1, L13.1, L14.1, L15.1, L16.1, L17.1, L18.1, L19.1, L20.1; also elsewhere on the board
1.2V_PLL1: C61.1, L6.2; also elsewhere on the board
1.2V_PLL2: C75.1, L10.2; also elsewhere on the board
1.2V_PLL3: C89.1, L11.2; also elsewhere on the board
1.2V_PLL4: C100.1, L12.2; also elsewhere on the board
1.2V_PLL5: C111.1, L13.2; also elsewhere on the board
1.2V_PLL6: C122.1, L14.2; also elsewhere on the board
1.2V_PLL7: C133.1, L15.2; also elsewhere on the board
1.2V_PLL8: C144.1, L16.2; also elsewhere on the board
1.2V_PLL9: C155.1, L17.2; also elsewhere on the board
1.2V_PLL10: C166.1, L18.2; also elsewhere on the board
1.2V_PLL11: C177.1, L19.2; also elsewhere on the board
1.2V_PLL12: C188.1, L20.2; also elsewhere on the board
3.3V: C62.1, C63.1, C76.1, C77.1, C90.1, C91.1, C101.1, C102.1, C112.1, C113.1, C123.1, C124.1, C134.1, C135.1, C145.1, C146.1, C156.1, C157.1, C167.1, C168.1, C178.1, C179.1, C189.1, C190.1; also elsewhere on the board
DGND: C61.2, C62.2, C63.2, C75.2, C76.2, C77.2, C89.2, C90.2, C91.2, C100.2, C101.2, C102.2, C111.2, C112.2, C113.2, C122.2, C123.2, C124.2, C133.2, C134.2, C135.2, C144.2, C145.2, C146.2, C155.2, C156.2, C157.2, C166.2, C167.2, C168.2, C177.2, C178.2, C179.2, C188.2, C189.2, C190.2; also elsewhere on the board
PGND: C64.2, C65.2, C66.2, C67.2, C68.2, C69.2, C70.2, C71.2, C78.2, C79.2, C80.2, C81.2, C82.2, C83.2, C84.2, C85.2, C92.2, C93.2, C94.2, C95.2, C96.2, C97.2, C98.2, C99.2, C103.2, C104.2, C105.2, C106.2, C107.2, C108.2, C109.2, C110.2, C114.2, C115.2, C116.2, C117.2, C118.2, C119.2, C120.2, C121.2, C125.2, C126.2, C127.2, C128.2, C129.2, C130.2, C131.2, C132.2, C136.2, C137.2, C138.2, C139.2, C140.2, C141.2, C142.2, C143.2, C147.2, C148.2, C149.2, C150.2, C151.2, C152.2, C153.2, C154.2, C158.2, C159.2, C160.2, C161.2, C162.2, C163.2, C164.2, C165.2, C169.2, C170.2, C171.2, C172.2, C173.2, C174.2, C175.2, C176.2, C180.2, C181.2, C182.2, C183.2, C184.2, C185.2, C186.2, C187.2, C191.2, C192.2, C193.2, C194.2, C195.2, C196.2, C197.2, C198.2; also elsewhere on the board

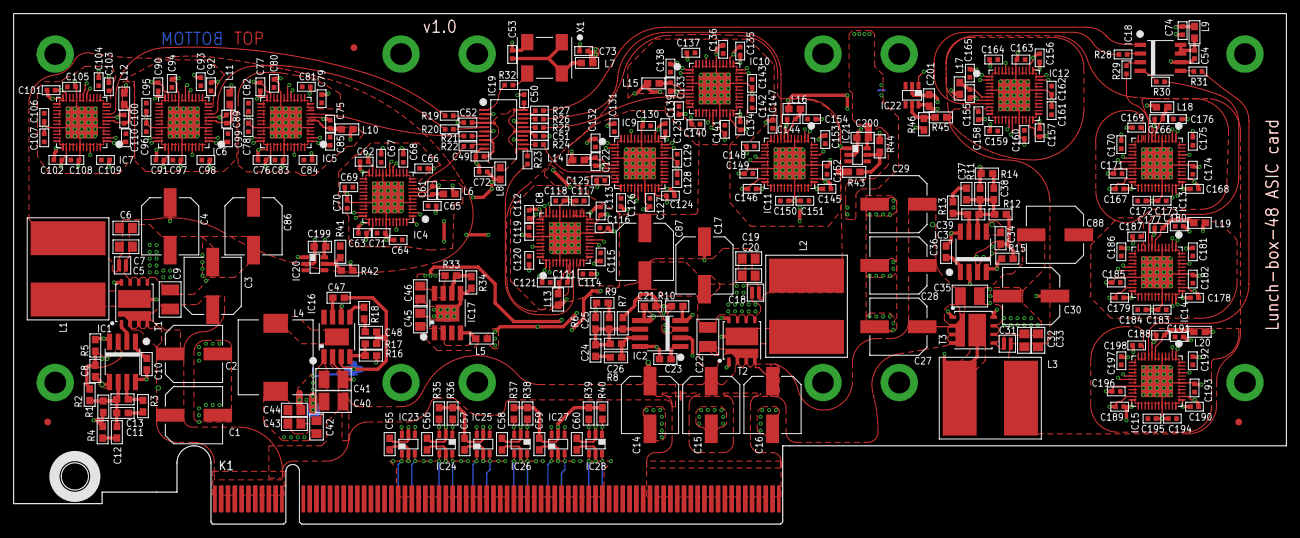
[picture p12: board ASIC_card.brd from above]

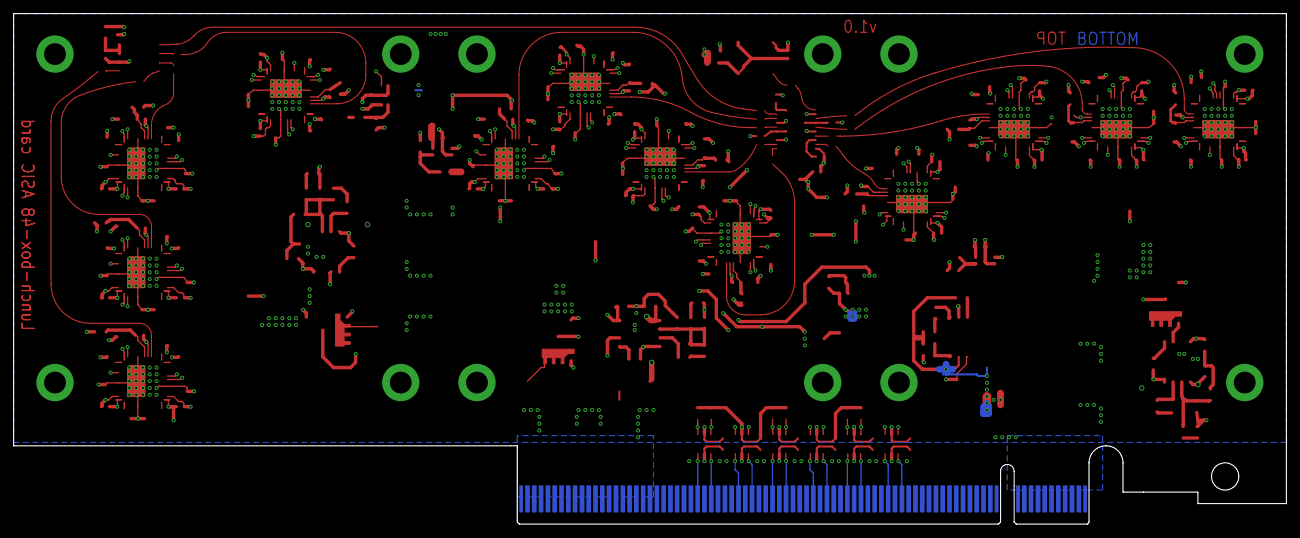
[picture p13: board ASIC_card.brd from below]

Board: 4 copper layers, 187.0 x 75.0 mm, 309 parts (3 on the bottom side), 131 nets.

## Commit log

2013-07-17 Asic card library added
    I added an Eagle 6 library which contains all of the symbols and
    packages of the Asic board design.
2013-09-03 Added v1 production files
    [ASIC_card.brd, ASIC_card.sch]
